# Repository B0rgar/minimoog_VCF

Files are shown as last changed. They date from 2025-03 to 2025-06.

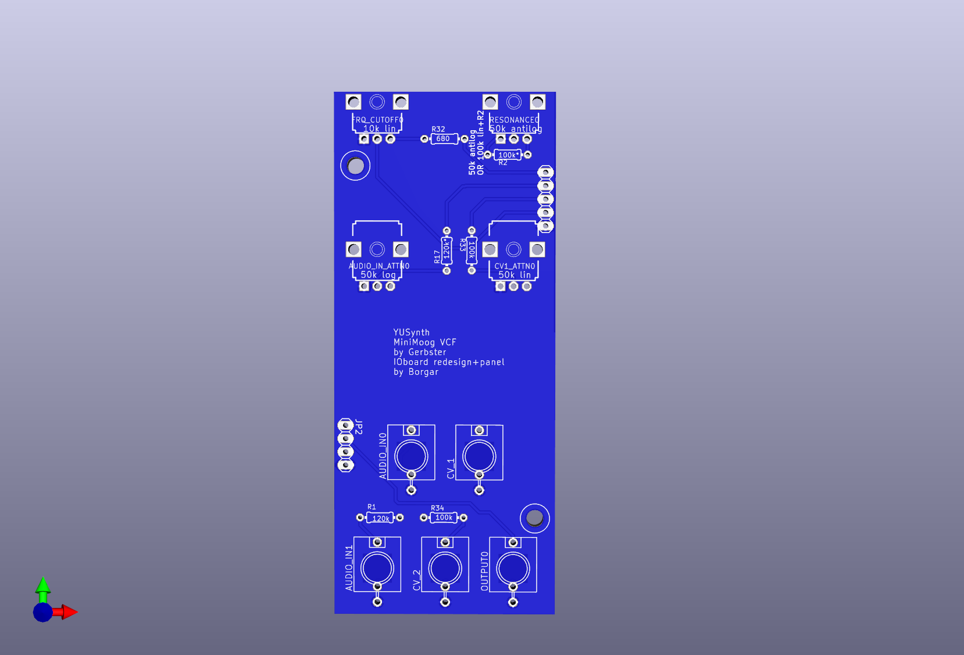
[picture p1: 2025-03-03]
Pictures/ioboard3d.png

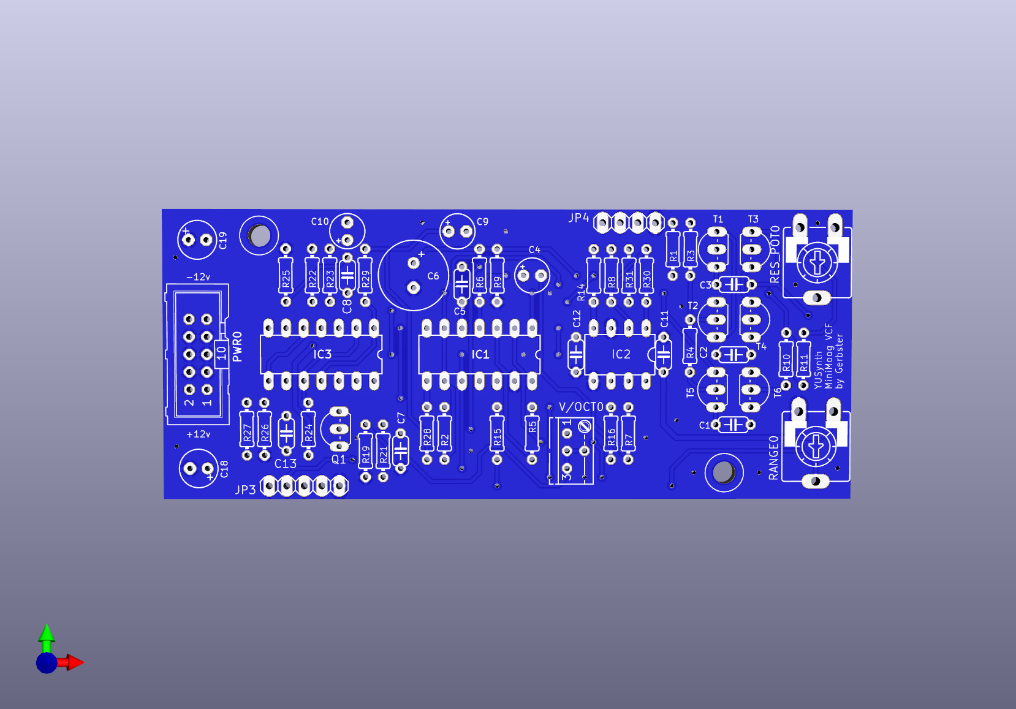
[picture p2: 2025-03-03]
Pictures/mainboard3d.png

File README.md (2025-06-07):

Thomas henry 555 vco with panel. based on Eagleproject from Gerbster.nl.

imported to kicad. IO board redesigned for a more logical layout and extra audio and CV input.

PCBS ordered from JLCPCB. will update after building and testing.

sm_blue_top
sm_blue_top (1)
sm_blue_top (2)

ioboard-panel-minimoog3d
ioboard3d
mainboard3d

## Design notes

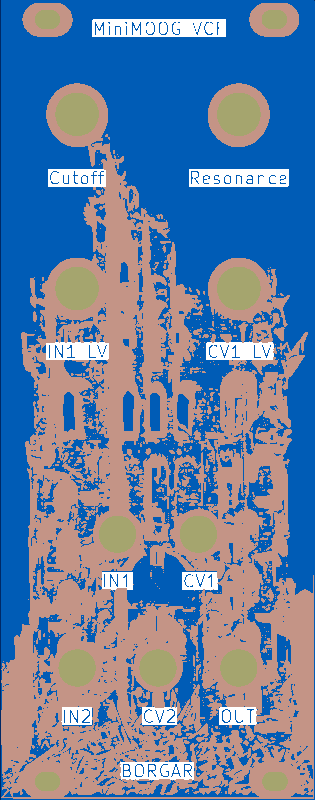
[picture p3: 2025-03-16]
Pictures/sm_blue_top.png

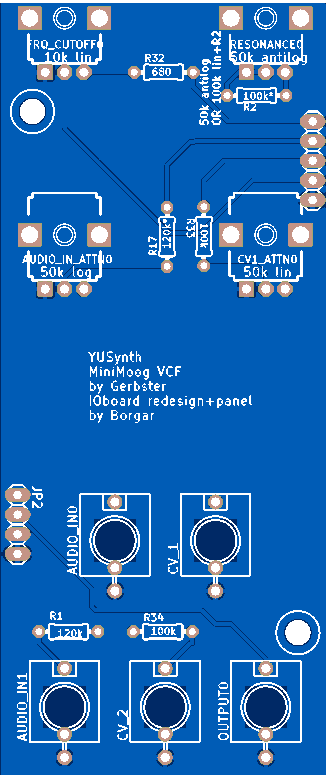
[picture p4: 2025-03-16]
Pictures/sm_blue_top (1).png

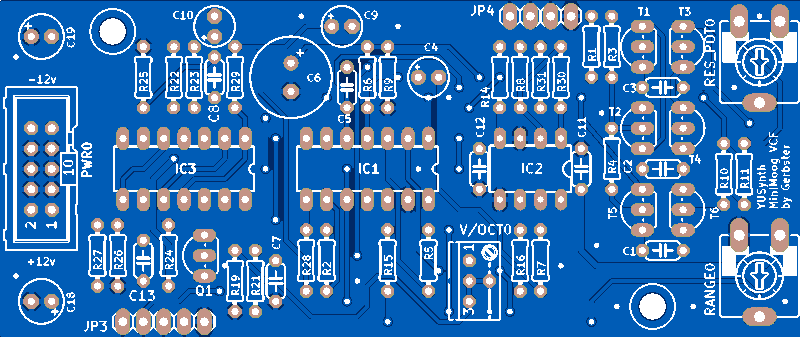
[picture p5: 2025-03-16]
Pictures/sm_blue_top (2).png

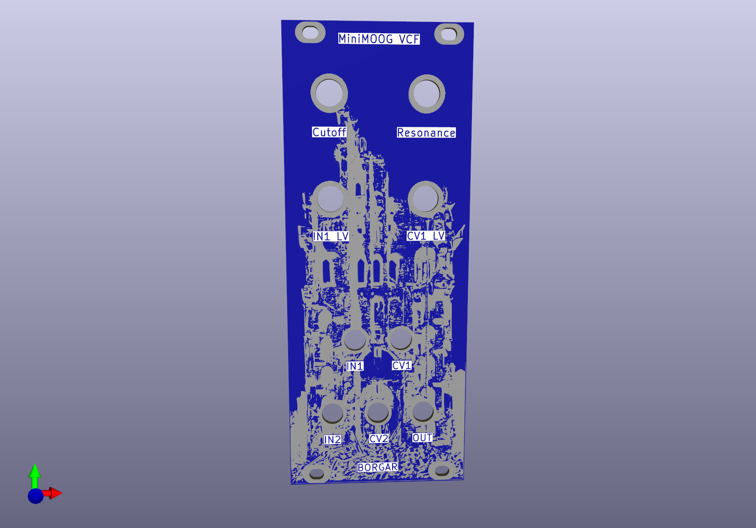
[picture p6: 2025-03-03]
Pictures/ioboard-panel-minimoog3d.png

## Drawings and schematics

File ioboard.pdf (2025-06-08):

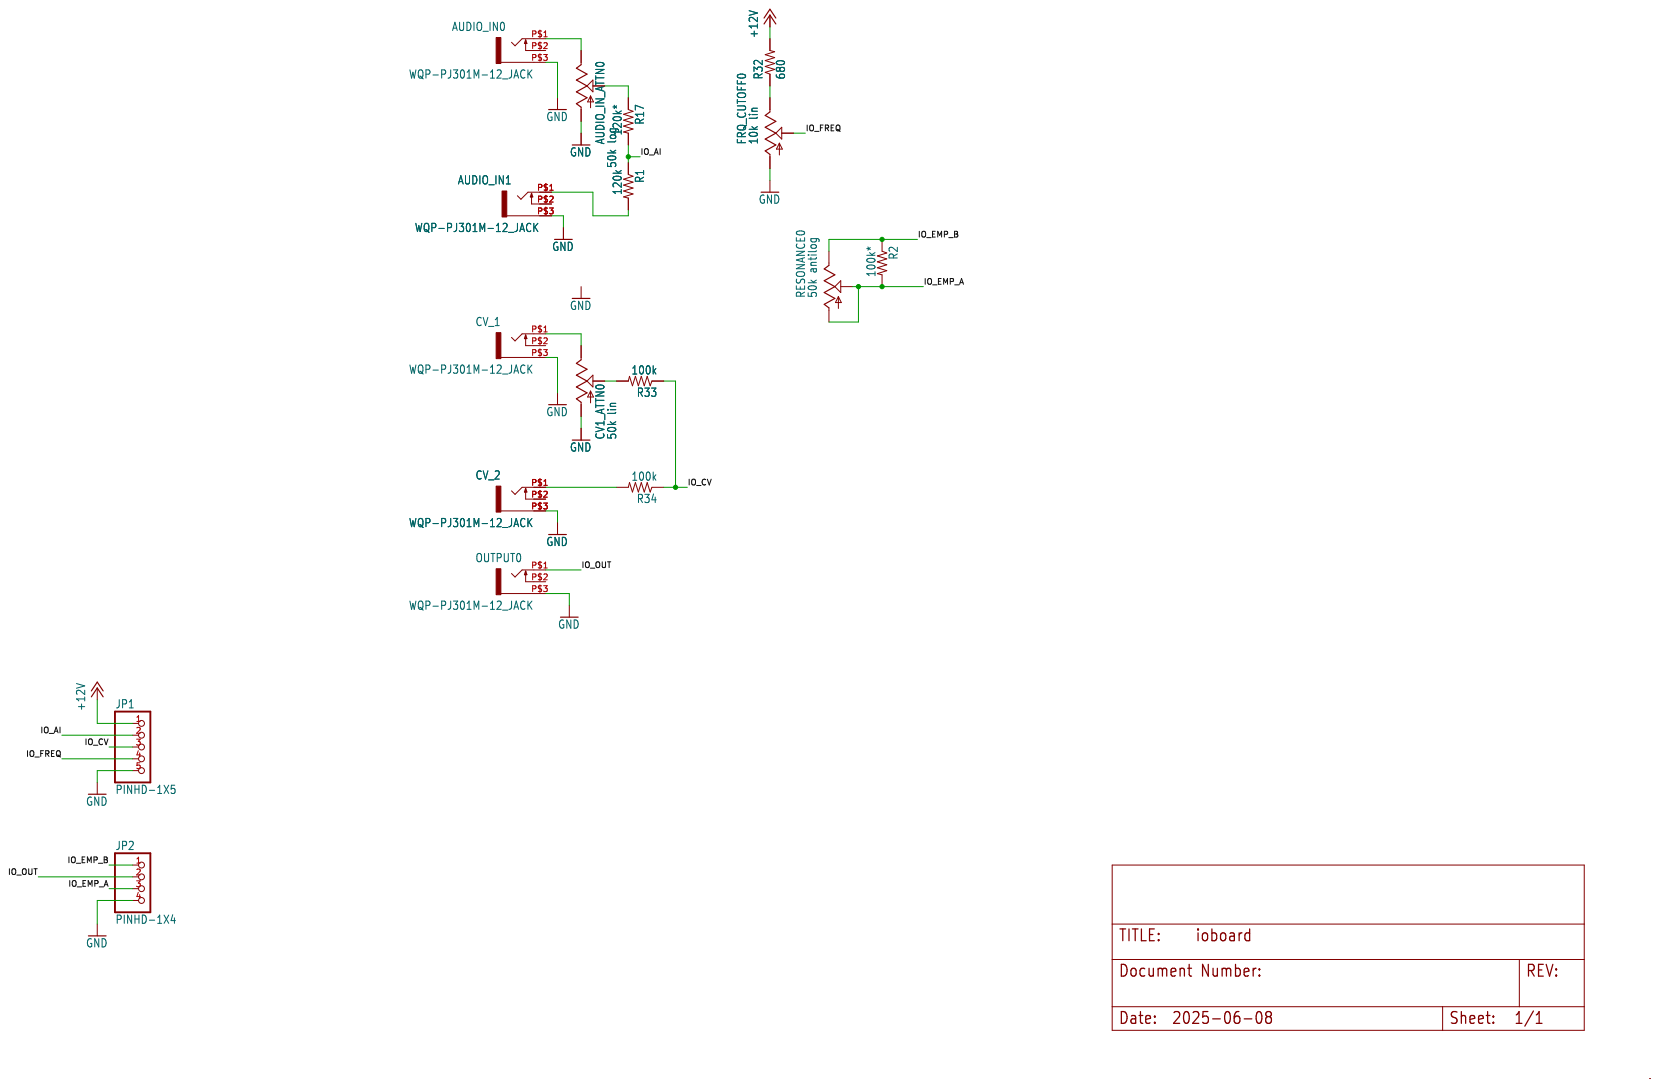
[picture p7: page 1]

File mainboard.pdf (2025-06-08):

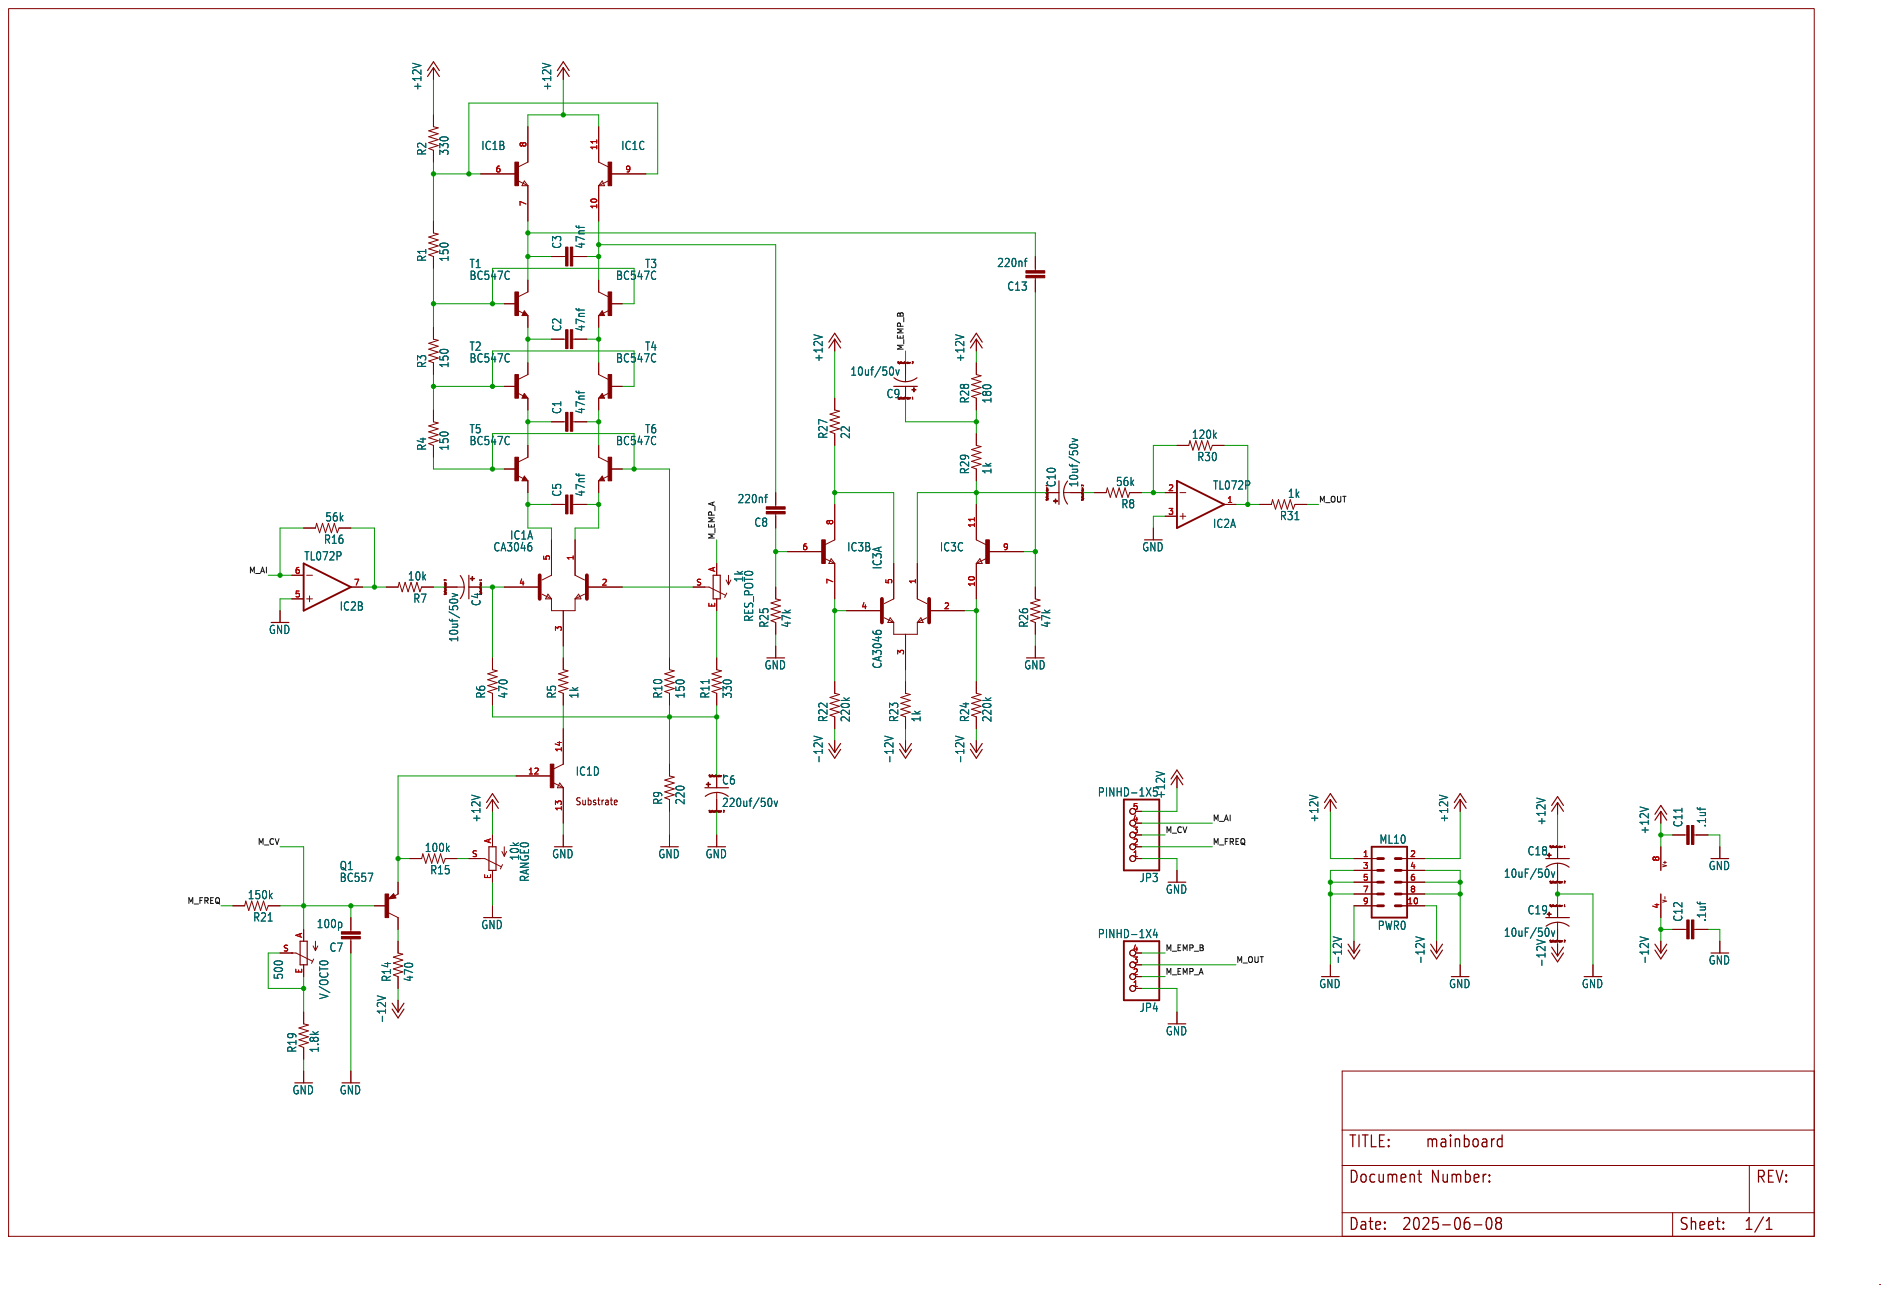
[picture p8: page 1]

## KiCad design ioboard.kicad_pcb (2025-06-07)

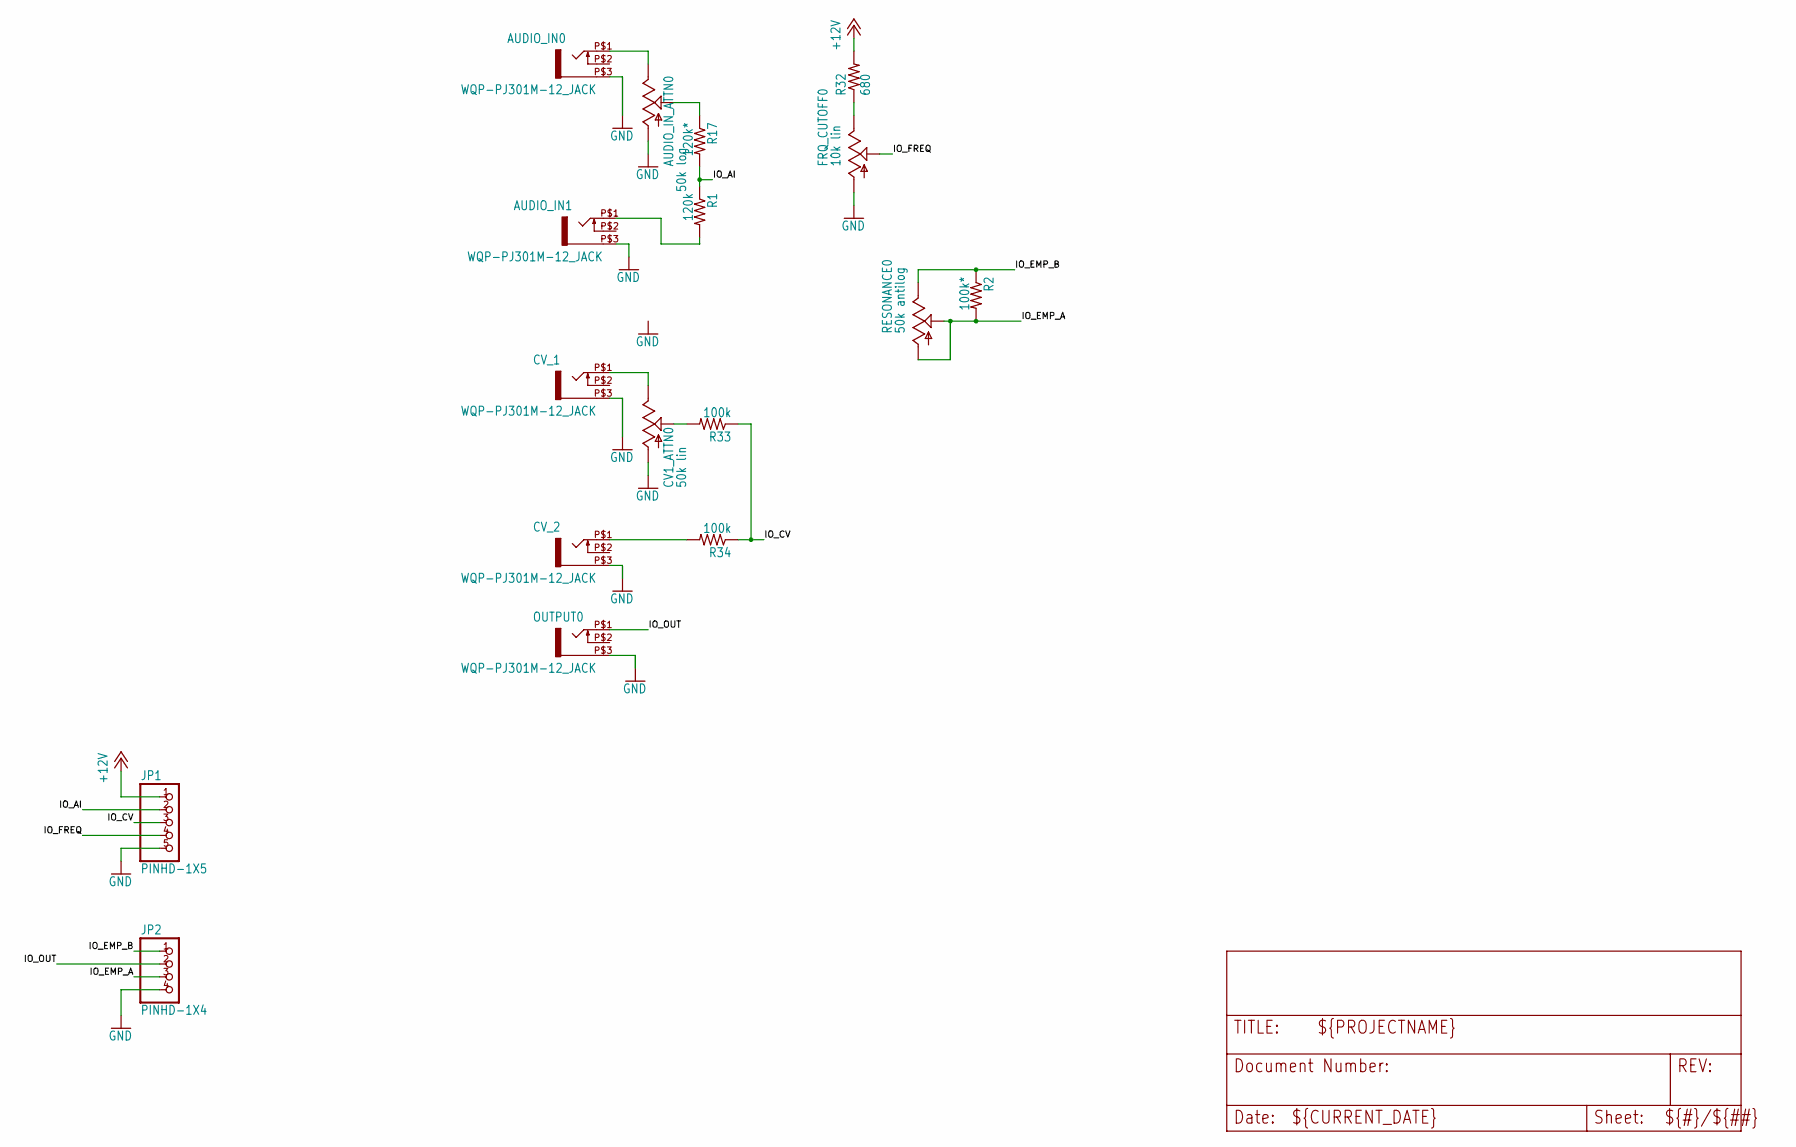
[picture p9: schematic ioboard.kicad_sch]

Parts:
AUDIO_IN0, AUDIO_IN1: WQP-PJ301M-12_JACK
AUDIO_IN_ATTN0: 50k log; EVUF
CV1_ATTN0: 50k lin; EVUF
CV_1, CV_2: WQP-PJ301M-12_JACK
FRQ_CUTOFF0: 10k lin; EVUF
JP1: PINHD-1X5; 1X05
JP2: PINHD-1X4; 1X04
OUTPUT0: WQP-PJ301M-12_JACK
R1: 120k; 0204_7
R2: 100k*; 0204_7
R17: 120k*; 0204_7
R32: 680; 0204_7
R33, R34: 100k; 0204_7
RESONANCE0: 50k antilog; EVUF

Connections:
+12V: JP1.1, R32.2
/IO_AI: JP1.2, R1.1, R17.2
/IO_CV: JP1.3, R33.1, R34.1
/IO_EMP_A: JP2.3, R2.2, RESONANCE0.1 (A), RESONANCE0.2 (S)
/IO_EMP_B: JP2.1, R2.1, RESONANCE0.3 (E)
/IO_FREQ: FRQ_CUTOFF0.2 (S), JP1.4
/IO_OUT: JP2.2, OUTPUT0.P$1 (2)
GND: AUDIO_IN0.P$3 (1), AUDIO_IN1.P$3 (1), AUDIO_IN_ATTN0.1 (A), CV1_ATTN0.1 (A), CV_1.P$3 (1), CV_2.P$3 (1), FRQ_CUTOFF0.1 (A), JP1.5, JP2.4, OUTPUT0.P$3 (1)
unnamed: AUDIO_IN0.P$1 (2), AUDIO_IN_ATTN0.3 (E)
unnamed: AUDIO_IN1.P$1 (2), R1.2
unnamed: AUDIO_IN_ATTN0.2 (S), R17.1
unnamed: CV1_ATTN0.3 (E), CV_1.P$1 (2)
unnamed: CV1_ATTN0.2 (S), R33.2
unnamed: CV_2.P$1 (2), R34.2
unnamed: FRQ_CUTOFF0.3 (E), R32.1

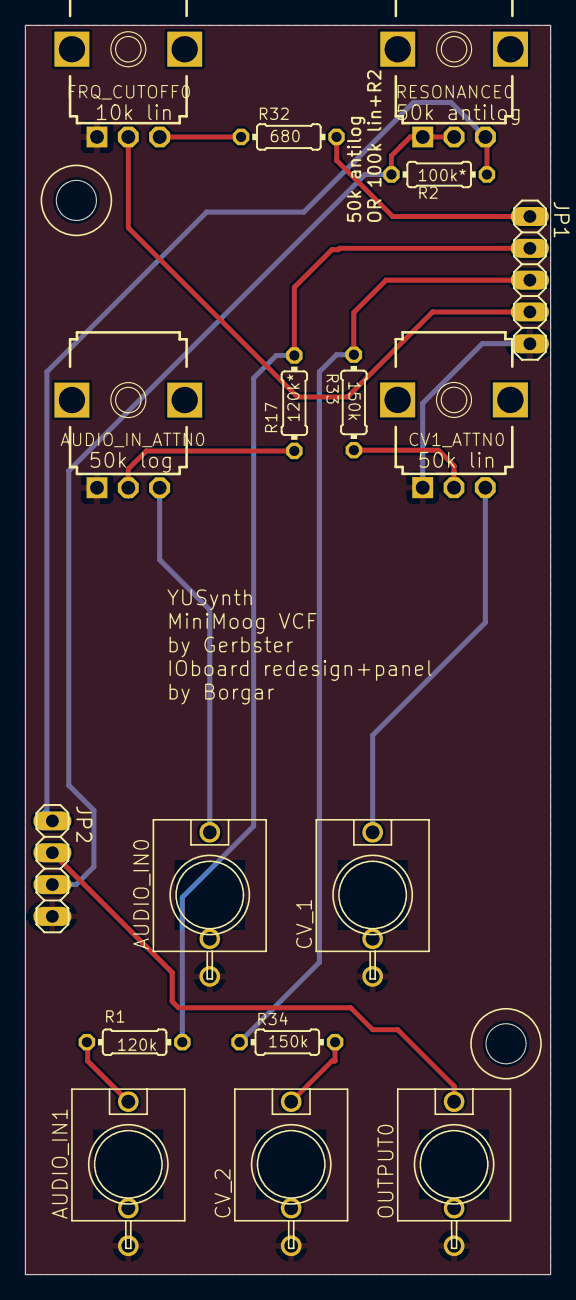
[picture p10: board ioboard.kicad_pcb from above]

Board: 2 copper layers, 41.9 x 99.7 mm, 19 parts (0 on the bottom side), 15 nets.

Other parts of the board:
@HOLE0, @HOLE1: (no value)

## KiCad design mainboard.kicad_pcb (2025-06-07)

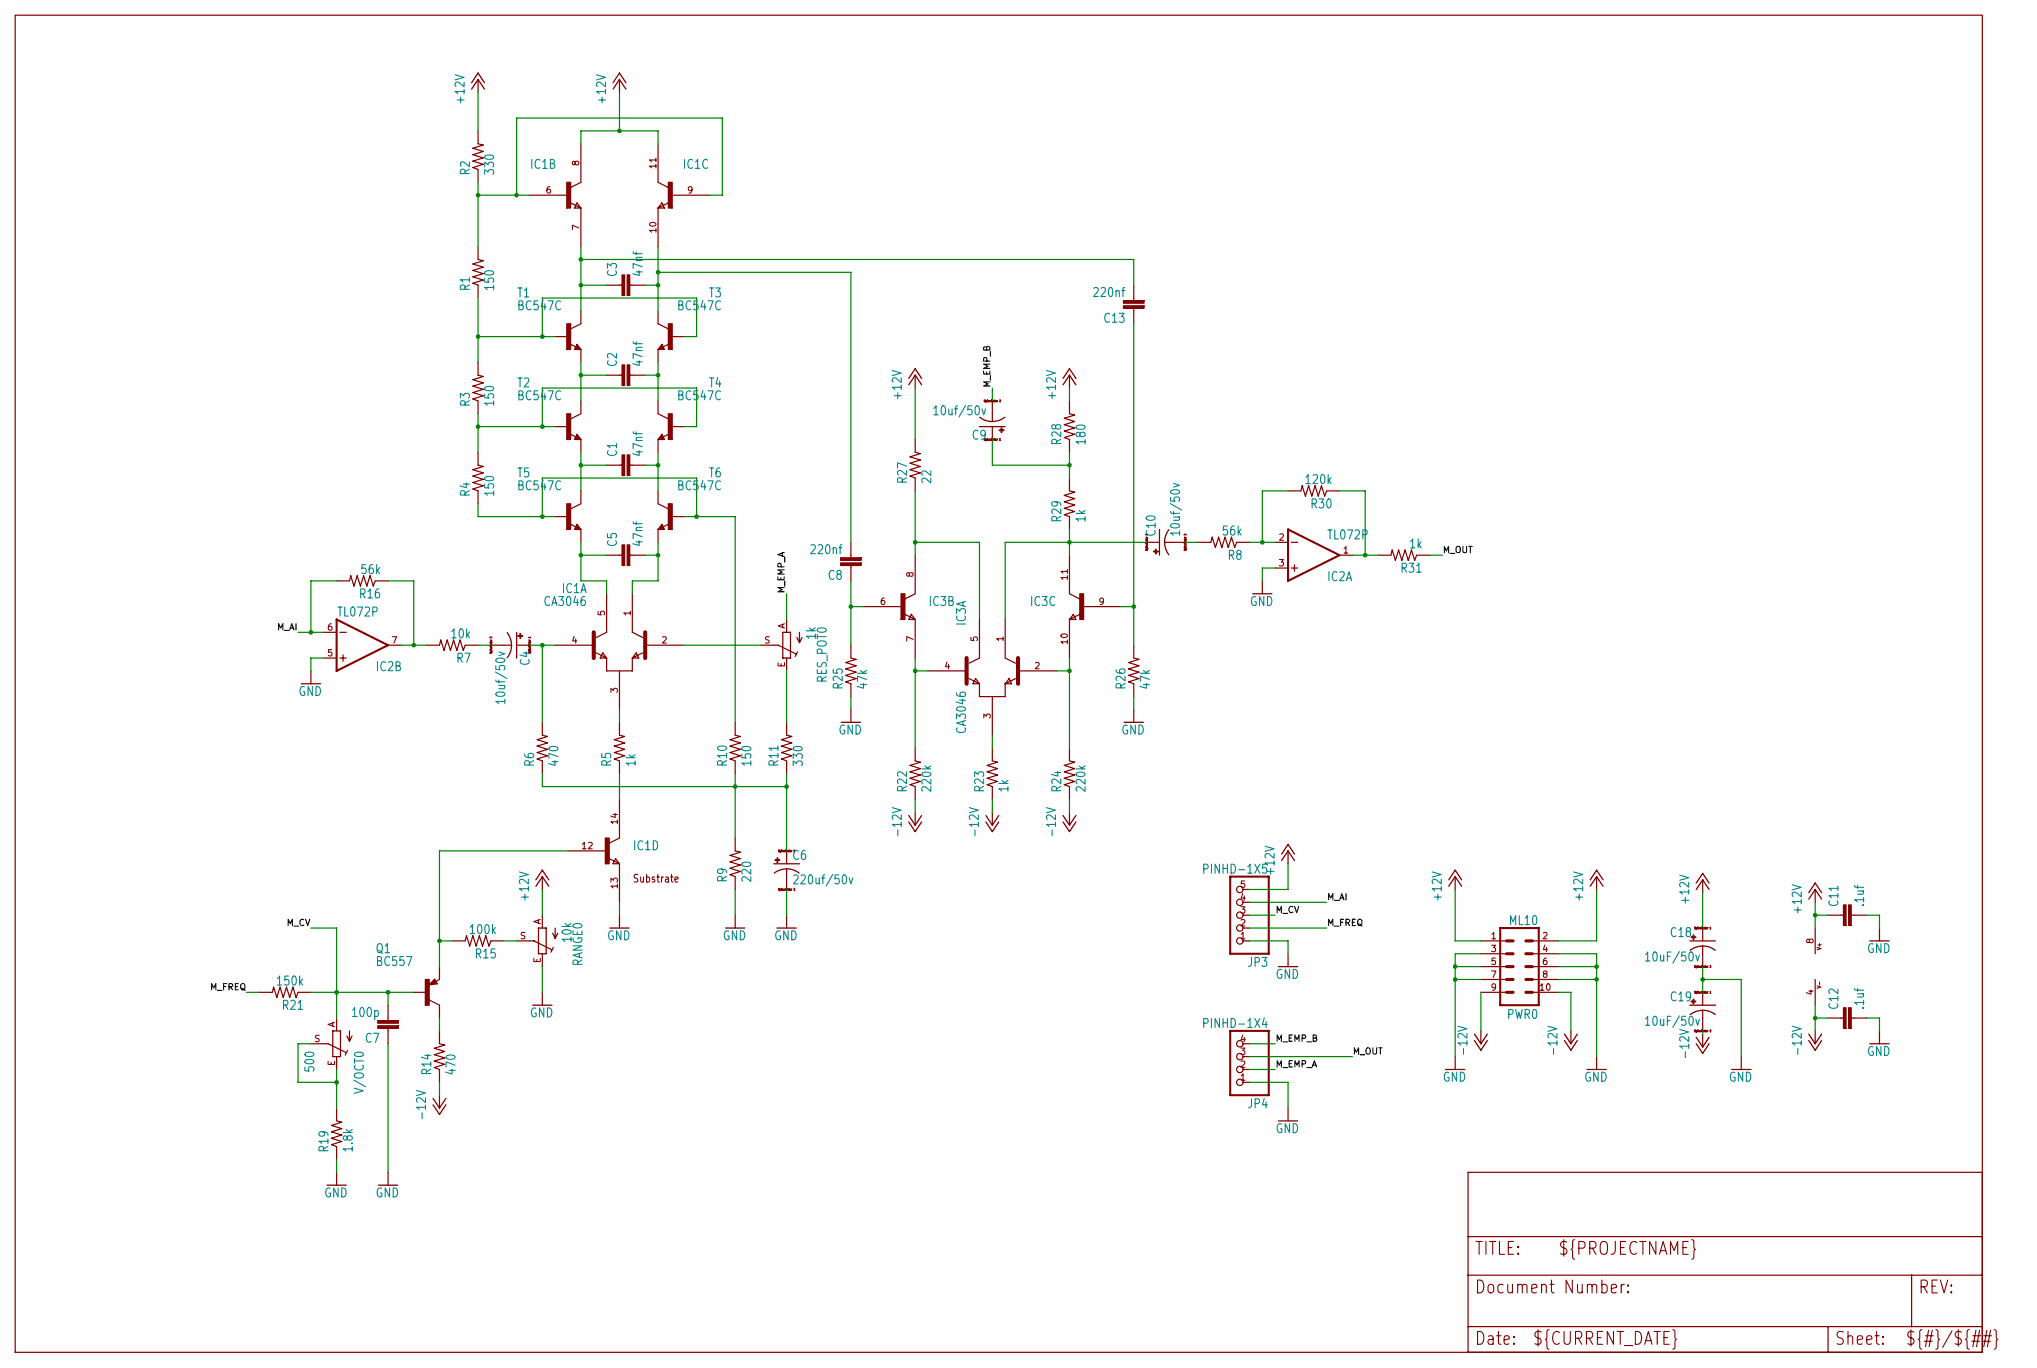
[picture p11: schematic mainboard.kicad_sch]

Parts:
C1, C2, C3, C5: 47nf; C050-024X044
C4, C9, C10: 10uf/50v; E2,5-5
C6: 220uf/50v; E3,5-10
C7: 100p; C050-024X044
C8, C13: 220nf; C050-024X044
C11, C12: .1uf; C050-024X044
C18, C19: 10uF/50v; E2,5-6
IC1, IC3: CA3046; DIL14
IC2: TL072P; DIL08
JP3: PINHD-1X5; 1X05
JP4: PINHD-1X4; 1X04
PWR0: ML10
Q1: BC557; TO92-EBC
R1, R3, R4, R10: 150; 0204_7
R2, R11: 330; 0204_7
R5, R23, R29, R31: 1k; 0204_7
R6, R14: 470; 0204_7
R7: 10k; 0204_7
R8, R16: 56k; 0204_7
R9: 220; 0204_7
R15: 100k; 0204_7
R19: 1.8k; 0204_7
R21: 150k; 0204_7
R22, R24: 220k; 0204_7
R25, R26: 47k; 0204_7
R27: 22; 0204_7
R28: 180; 0204_7
R30: 120k; 0204_7
RANGE0: 10k; CA9V
RES_POT0: 1k; CA9V
T1, T2, T3, T4, T5, T6: BC547C; TO92-CBE
V/OCT0: 500; S64YW

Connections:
+12V: C11.1, C18.+, IC1.8 (C), IC1.11 (C), IC2.8 (V+), JP3.5, PWR0.1, PWR0.2, R2.2, R27.2, R28.2, RANGE0.A
-12V: C12.1, C19.-, IC2.4 (V-), PWR0.9, PWR0.10, R14.1, R22.1, R23.1, R24.1
GND: C6.-, C7.1, C11.2, C12.2, C18.-, C19.+, IC1.13 (E), IC2.3 (+IN), IC2.5 (+IN), JP3.1, JP4.1, PWR0.3, PWR0.4, PWR0.5, PWR0.6, PWR0.7, PWR0.8, R9.1, R19.1, R25.1, R26.1, RANGE0.E
M_AI: IC2.6 (-IN), JP3.4, R16.2
M_CV: C7.2, JP3.3, Q1.B, R21.1, V/OCT0.A
M_EMP_A: JP4.2, RES_POT0.A
M_EMP_B: C9.-, JP4.4
M_FREQ: JP3.2, R21.2
M_OUT: JP4.3, R31.1
unnamed: C5.1, IC1.5 (C2), T5.E
unnamed: IC1.6 (B), IC1.9 (B), R1.2, R2.1
unnamed: C3.1, C13.2, IC1.7 (E), T1.C
unnamed: C3.2, C8.2, IC1.10 (E), T3.C
unnamed: C2.1, T1.E, T2.C
unnamed: C2.2, T3.E, T4.C
unnamed: C1.1, T2.E, T5.C
unnamed: C1.2, T4.E, T6.C
unnamed: R1.1, R3.2, T1.B, T3.B
unnamed: R3.1, R4.2, T2.B, T4.B
unnamed: R4.1, R10.2, T5.B, T6.B
unnamed: C5.2, IC1.1 (C1), T6.E
unnamed: IC1.3 (E), R5.2
unnamed: IC1.14 (C), R5.1
unnamed: C4.+, IC1.4 (B2), R6.2
unnamed: C4.-, R7.1
unnamed: C6.+, R6.1, R9.2, R10.1, R11.1
unnamed: IC2.7 (OUT), R7.2, R16.1
unnamed: R19.2, V/OCT0.E, V/OCT0.S
unnamed: IC1.12 (B), Q1.E, R15.2
unnamed: IC1.2 (B1), RES_POT0.S
unnamed: R11.2, RES_POT0.E
unnamed: C13.1, IC3.9 (B), R26.2
unnamed: Q1.C, R14.2
unnamed: R15.1, RANGE0.S
unnamed: C10.-, R8.2
unnamed: IC3.4 (B2), IC3.7 (E), R22.2
unnamed: IC3.3 (E), R23.2
unnamed: IC3.2 (B1), IC3.10 (E), R24.2
unnamed: IC3.5 (C2), IC3.8 (C), R27.1
unnamed: C10.+, IC3.1 (C1), IC3.11 (C), R29.1
unnamed: C9.+, R28.1, R29.2
unnamed: IC2.1 (OUT), R30.1, R31.2
unnamed: C8.1, IC3.6 (B), R25.2
unnamed: IC2.2 (-IN), R8.1, R30.2

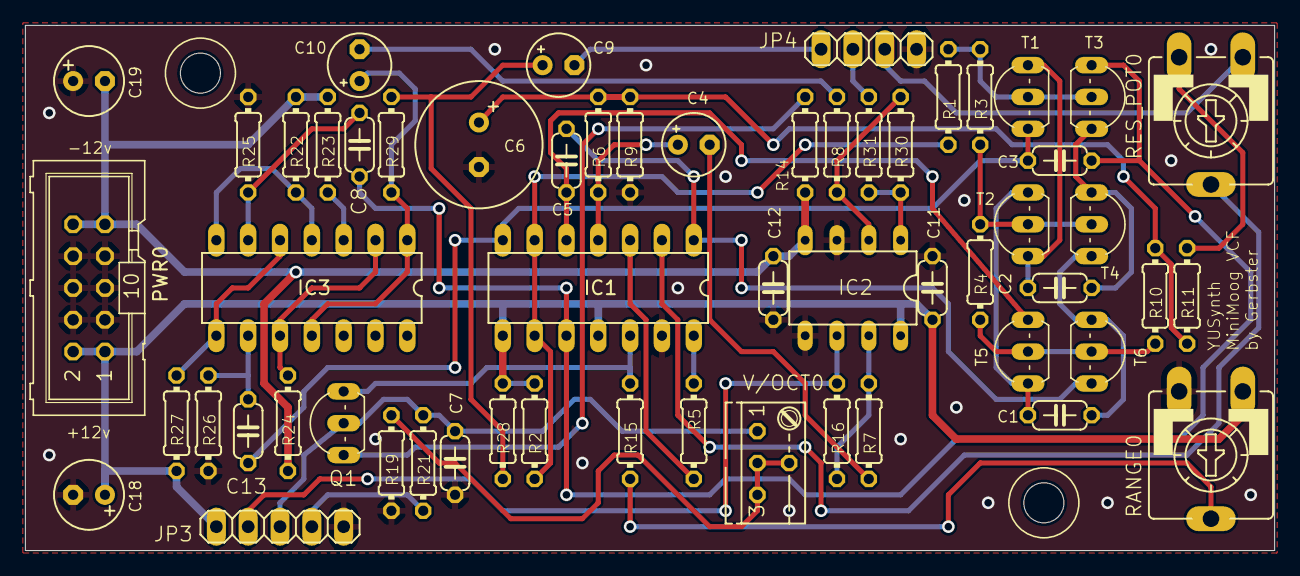
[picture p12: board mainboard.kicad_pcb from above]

Board: 2 copper layers, 99.7 x 41.9 mm, 59 parts (0 on the bottom side), 44 nets.

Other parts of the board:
@HOLE0, @HOLE1: (no value)
